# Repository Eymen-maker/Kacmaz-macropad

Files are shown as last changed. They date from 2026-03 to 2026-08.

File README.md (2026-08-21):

HIII, this macropad is fully self/custom made. It has 6 keys and uses a Seeed XIAO RP2040 for software it uses QMK.

How to flash: just put .uf2 file in the microcontroller file (drag and drop).
In the current compiled code it says: 

key 1: 1

key 2: 2

key 3: 3

key 4: Hello, my name ıs Eymen. 

key 5: 5

key 6: 6

so it can write macros as well but be careful your keyboards language setting can break some words.

parts for the pcb are 6 through-hole 1N4148 Diodes, 6 MX-Style switches, 1 Seeed XIAO RP2040 and for the case you can use 4x M3x16mm screws, 4x M3x5mx4mm heatset inserts and the case would be 3d printed. (i didn't build the case for this example)





WhatsApp Image 2026-08-18 at 23 55 25

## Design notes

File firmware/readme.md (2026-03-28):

# en_kacmaz_macropad_2

en_kacmaz_macropad_2

*A short description of the keyboard/project*

* Keyboard Maintainer: [Eymen](https://github.com/eymen-maker)
* Hardware Supported: *The PCBs, controllers supported*
* Hardware Availability: *Links to where you can find this hardware*

Make example for this keyboard (after setting up your build environment):

    make en_kacmaz_macropad_2:default

Flashing example for this keyboard:

    make en_kacmaz_macropad_2:default:flash

See the [build environment setup](https://docs.qmk.fm/#/getting_started_build_tools) and the [make instructions](https://docs.qmk.fm/#/getting_started_make_guide) for more information. Brand new to QMK? Start with our [Complete Newbs Guide](https://docs.qmk.fm/#/newbs).

## Bootloader

Enter the bootloader in 3 ways:

* **Bootmagic reset**: Hold down the key at (0,0) in the matrix (usually the top left key or Escape) and plug in the keyboard
* **Physical reset button**: Briefly press the button on the back of the PCB - some may have pads you must short instead
* **Keycode in layout**: Press the key mapped to `QK_BOOT` if it is available

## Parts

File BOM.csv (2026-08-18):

NAME | LINKS
seeed studio XIAO - RP2040 | https://www.robotistan.com/seeed-studio-xiao-rp2040-gelistirmekarti
diode 1n4148 | https://www.robotistan.com/1n4148-100v-450ma-aksiyel-tipli-hizli-diyot
6 red switc | https://www.trendyol.com/spelt/outemu-kirmizi-mekanik-klavye-red-switch-yedek-tus-6-adet-p-54533028

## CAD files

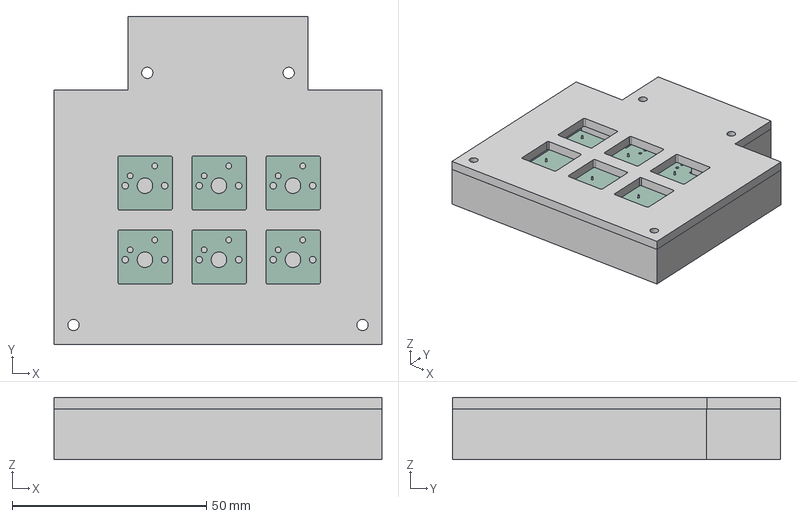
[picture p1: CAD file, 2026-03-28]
CAD source file/Kacmaz_macropad.step
84.4 x 84.4 x 16.0 mm
D_DO-35_SOD27_P7.62mm_Horizontal x 6
third_attempt_macropad_PCB

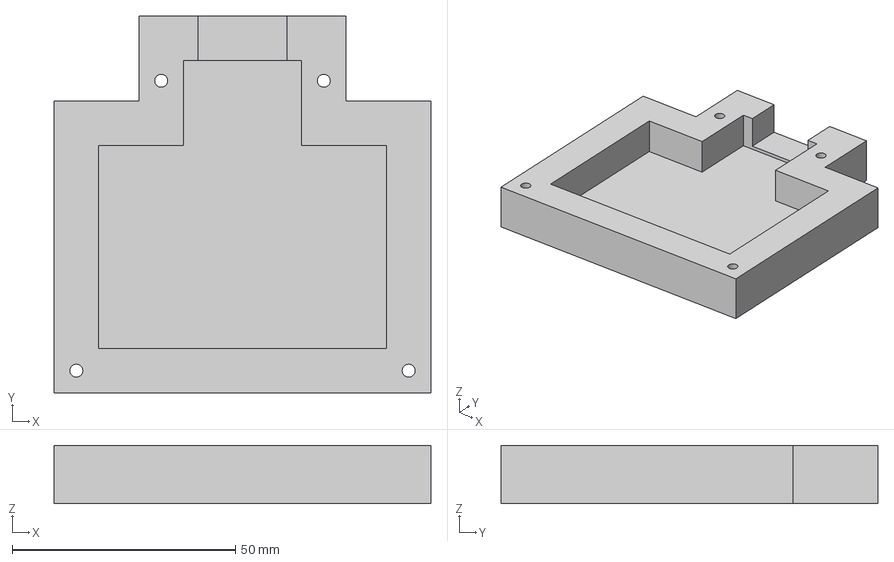
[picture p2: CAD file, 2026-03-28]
production/CAD/kacmaz macropad 3d bottom.step
84.4 x 84.4 x 13.0 mm

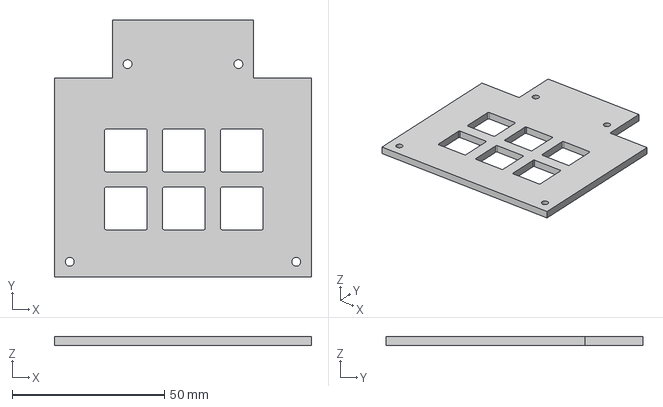
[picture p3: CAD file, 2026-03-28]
production/CAD/kacmaz macropad 3d top.step
84.4 x 84.4 x 3.00 mm

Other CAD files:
production/CAD/kacmaz macropad 3d bottom .stl
production/CAD/kacmaz macropad 3d top.stl

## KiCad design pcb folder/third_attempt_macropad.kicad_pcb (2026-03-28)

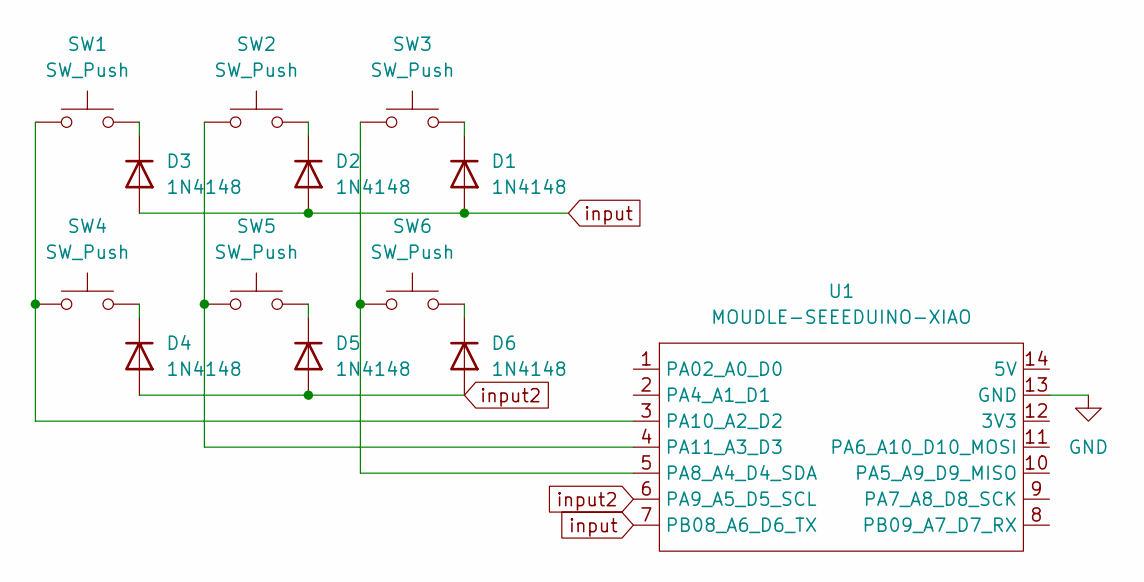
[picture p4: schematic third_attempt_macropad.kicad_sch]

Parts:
D1, D2, D3, D4, D5, D6: 1N4148; D_DO-35_SOD27_P7.62mm_Horizontal
SW1, SW2, SW3, SW4, SW5, SW6: SW_Push; SW_Cherry_MX_1.00u_PCB
U1: MOUDLE-SEEEDUINO-XIAO; XIAO-Generic-Hybrid-14P-2.54-21X17.8MM

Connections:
GND: U1.13 (GND)
unnamed: D1.1 (K), SW3.2
unnamed: D2.1 (K), SW2.2
unnamed: D3.1 (K), SW1.2
unnamed: D4.1 (K), SW4.2
unnamed: D5.1 (K), SW5.2
unnamed: D6.1 (K), SW6.2
unnamed: SW3.1, SW6.1, U1.5 (PA8_A4_D4_SDA)
unnamed: SW1.1, SW4.1, U1.3 (PA10_A2_D2)
unnamed: SW2.1, SW5.1, U1.4 (PA11_A3_D3)
el input: D1.2 (A), D2.2 (A), D3.2 (A), U1.7 (PB08_A6_D6_TX)
el input2: D4.2 (A), D5.2 (A), D6.2 (A), U1.6 (PA9_A5_D5_SCL)

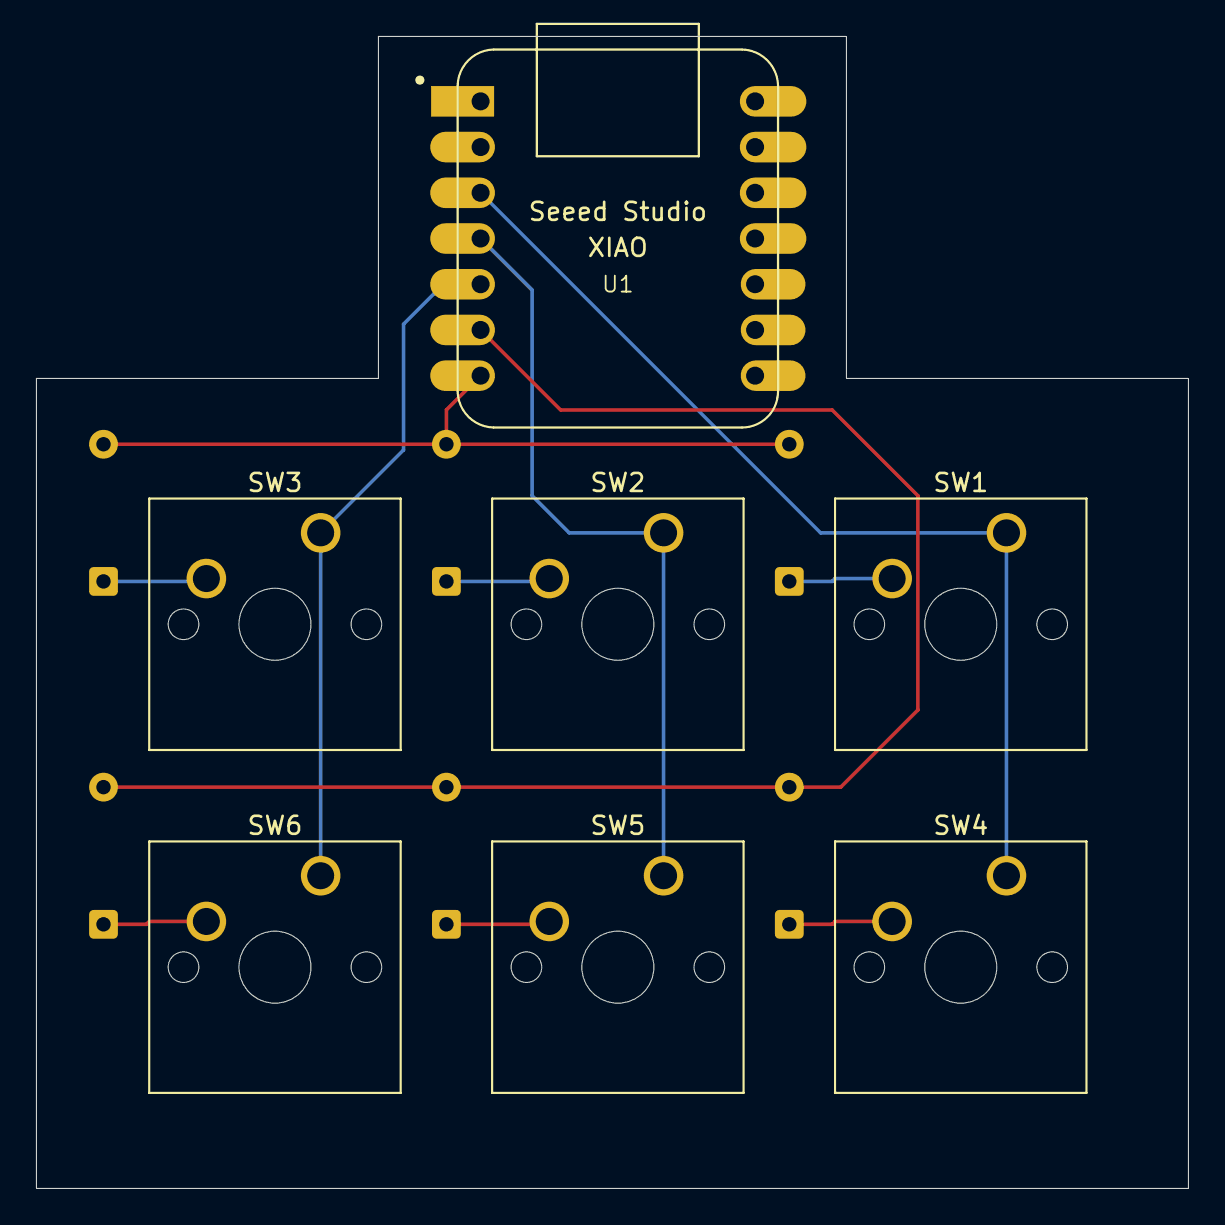
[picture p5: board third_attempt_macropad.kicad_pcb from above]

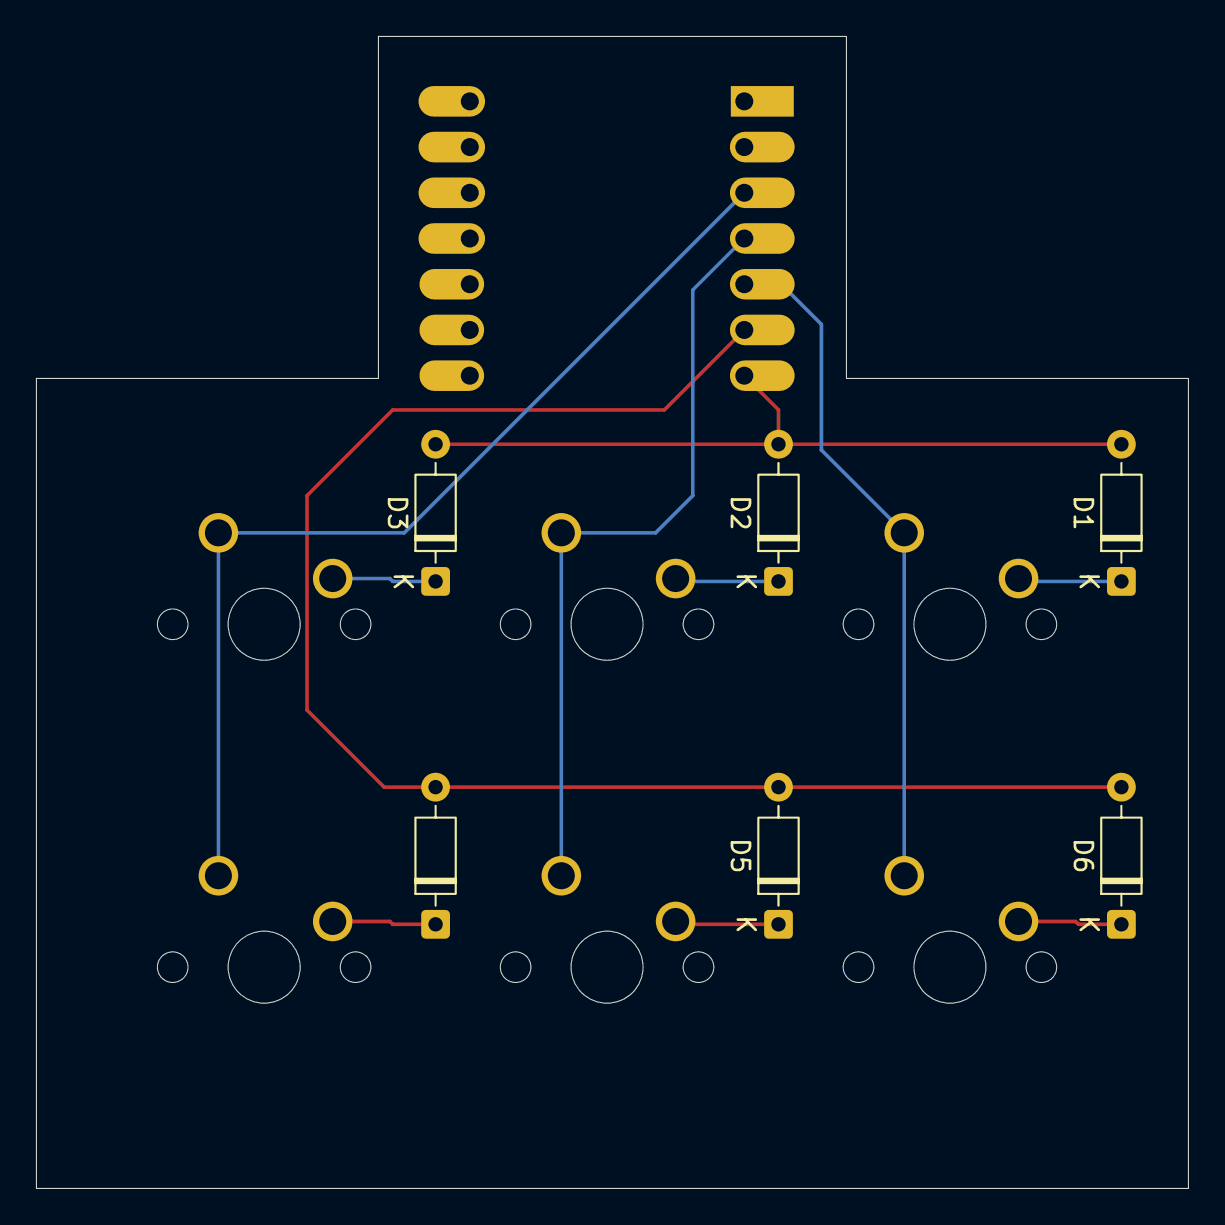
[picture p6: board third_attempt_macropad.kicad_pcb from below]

Board: 2 copper layers, 64.0 x 64.0 mm, 13 parts (6 on the bottom side), 11 nets.

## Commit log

2026-08-18 Added BOM
    [BOM.csv]
2026-08-18 added the correct BOM
    [BOM.csv]
2026-08-19 adding gerber file again
2026-08-19 CAD source file
    [Kacmaz_macropad.step]
2026-08-21 added source cad in .stl format
